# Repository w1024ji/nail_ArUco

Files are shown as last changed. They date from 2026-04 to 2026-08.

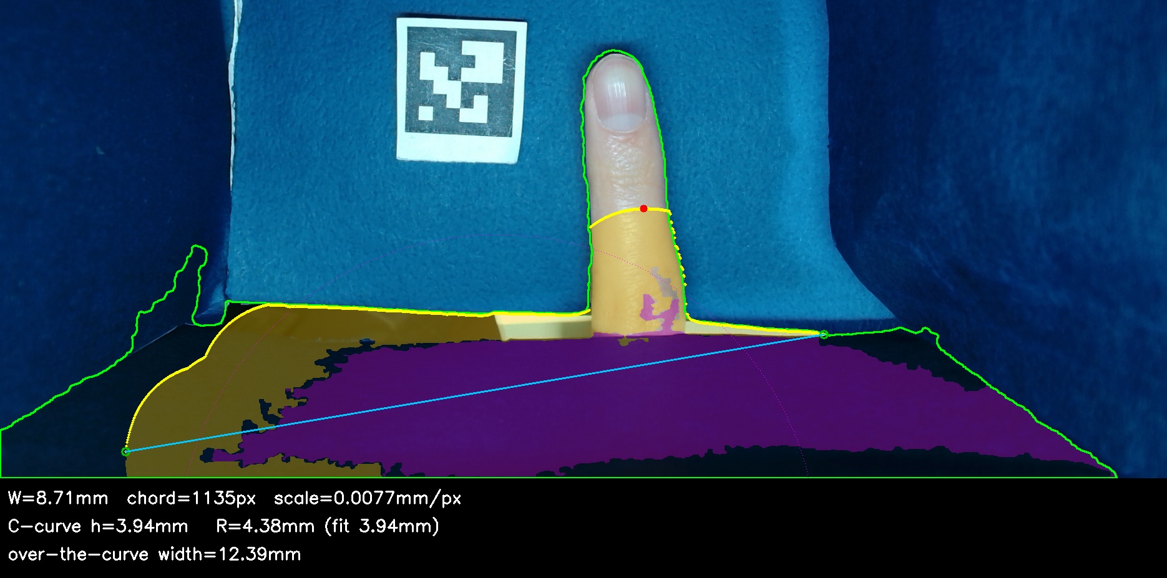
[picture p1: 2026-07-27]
scan/out_live/index_ccurve_debug.jpg

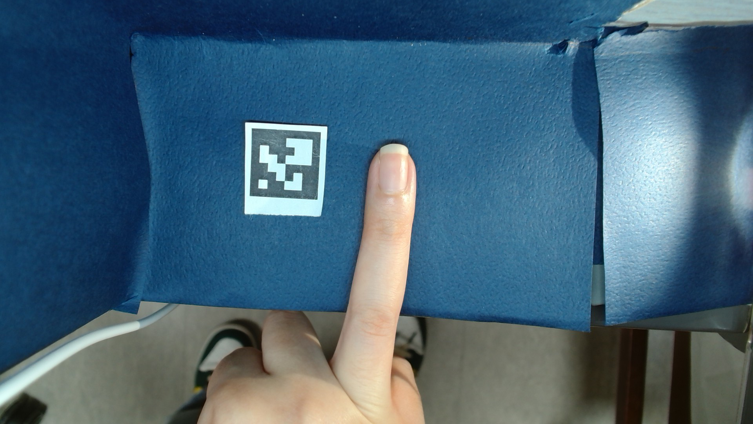
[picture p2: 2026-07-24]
scan/test/test_ring_a.jpg

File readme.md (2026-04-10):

# Nail Measurement Tool
### ArUco-based · 5 fingers · JSON output for 3-D mesh pipeline

---
## commands
```bash
python nail_measurer.py --image fingers_left.jpg --aruco-size 20 --output my_results_left
python nail_tip_generator.py --measurements nail_measurements.json --hand right --curve flat
python nail_tip_generator.py --measurements nail_measurements.json --hand right --curve medium
python nail_tip_generator.py --measurements nail_measurements.json --hand right --curve steep
```

---

## Install

```bash
pip install opencv-python opencv-contrib-python numpy scipy
```
Python 3.10+ recommended.

---

## Quick-start workflow

### 1 · Print a marker

```bash
python generate_aruco.py --size 20 --id 0 --output marker.png
```
- Print `marker.png` at **100 % scale** (no "fit to page").
- Verify the inner black square with calipers. Note the exact mm value.

### 2 · Take the photo

| ✅ Do | ❌ Avoid |
|---|---|
| Hand flat, palm down | Tilted or angled shots |
| Marker in the same plane as nails | Marker propped up / on a book |
| Diffuse even lighting | Harsh shadows across nails |
| Plain light-coloured background | Patterned tablecloth |
| Shoot straight down (top-view) | Side angle |
| 12 MP+ camera | Low-res or blurry |

### 3 · Run auto-detection

```bash
python nail_measurer.py --image hand.jpg --aruco-size 20.3 --output results/
```
*(use your actual caliper measurement for `--aruco-size`)*

Output: `results/nail_measurements.json`

### 4 · Manual fallback (painted nails / poor lighting)

```bash
python manual_selector.py --image hand.jpg --aruco-size 20.3 --output results/
```
- **Left-click** to place outline points around a nail
- **Right-click** to save and move to the next finger
- **`u`** to undo last point
- **`n`** to skip a finger
- **`q`** or **ESC** to finish

---

## JSON output structure

```jsonc
{
  "meta": {
    "source_image": "hand.jpg",
    "aruco_marker_id": 0,
    "aruco_physical_size_mm": 20.3,
    "mm_per_pixel": 0.07314,
    "nails_detected": 5,
    "measurement_notes": { ... }   // explains each field
  },

  // Full detail per nail
  "nails": [
    {
      "finger":            "thumb",
      "finger_id":         0,
      "length_mm":         16.4,
      "width_mm":          14.2,
      "c_curve_mm":        2.3,     // arc depth (sagitta)
      "arc_radius_mm":     23.1,    // radius of curvature
      "thickness_mm":      0.45,    // estimated (see note)
      "thickness_source":  "geometric_estimate",
      "aspect_ratio":      0.866,
      "pixel_scale_mm_per_px": 0.07314,
      "nail_polygon_px":   [[x,y], ...]
    }
    // ... index, middle, ring, pinky
  ],

  // Quick lookup by finger name
  "by_finger": {
    "thumb":  { "length_mm": 16.4, "width_mm": 14.2, ... },
    ...
  },

  // Ready-to-use 3-D mesh parameters
  "mesh_params": {
    "thumb": {
      "bounding_box_mm": { "x": 14.2, "y": 0.45, "z": 16.4 },
      "curvature": {
        "c_curve_sagitta_mm": 2.3,
        "arc_radius_mm":      23.1
      },
      "shape_hint": "barrel_arc  AR=0.866"
    },
    ...
  }
}
```

---

## Measurements explained

| Field | Definition | How it's computed |
|---|---|---|
| `length_mm` | Base-to-tip along the nail's long axis | Rotated bounding box long side |
| `width_mm` | Widest point across the nail | Rotated bounding box short side |
| `c_curve_mm` | Arc depth (sagitta) — how much the nail curves across its width | Max perpendicular deviation from the width chord |
| `arc_radius_mm` | Radius of the circular arc | Sagitta formula: R = w²/(8h) + h/2 |
| `thickness_mm` | Nail plate thickness base-to-surface | Estimated: c_curve × 1.5, clamped to 0.25–0.85 mm |

### Thickness note
Thickness **cannot** be measured from a top-down photo alone.
The value in the JSON is a geometric estimate based on nail anatomy research
(average human nail: 0.35–0.65 mm).
For precision 3-D printing, measure thickness from a **side-view** photo:
```bash
# future: side_view_measurer.py --image thumb_side.jpg --aruco-size 20.3
```
Then manually update `thickness_mm` in the JSON.

---

## Using the JSON in your 3-D pipeline

The `mesh_params` block gives you everything needed to construct a parametric nail mesh:

```python
import json

with open("nail_measurements.json") as f:
    data = json.load(f)

for finger, params in data["mesh_params"].items():
    bb  = params["bounding_box_mm"]   # x=width, y=thickness, z=length
    R   = params["curvature"]["arc_radius_mm"]
    h   = params["curvature"]["c_curve_sagitta_mm"]
    # → feed bb + R into your parametric nail mesh generator
```

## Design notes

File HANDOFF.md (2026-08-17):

# Nail ArUco — Handoff (2026-08-10)

Custom nail-tip generator: photo of a finger → real-world measurements → 3D-printable STL. Written for picking this project back up on a new Claude account. Repo: `/mnt/c/nail_ArUco`, branch `nail-shape-detection`.

## Pipeline

1. **Photo/Capture** — one finger per shot, finger pointing up, ArUco marker (6x6_50 dict) beside it on the same flat surface, dark background.
   - `scan/nail_capture.py` — auto-capture still-photo flow (marker stability + skin-fraction gate before countdown).
   - `scan/nail_live.py` — **preferred now.** Runs measurement continuously on the live camera feed; operator presses ENTER to accept the measurement they're looking at (not a raw photo to be judged blind afterwards). Has a `--rotate {0,90,180,270}` flag because the rig's camera is mounted upside down. Shows a live fold-coverage meter and a peak-width tracker (see below).
2. **Measure** — `scan/nail_measurer.py` (the core, heavily-tuned module). ArUco gives mm/px scale; then detects finger silhouette, nail width (lateral folds), length, cuticle position, and c-curve. Outputs `nail_measurements.json` + `profile.json` + annotated image.
3. **C-curve (separate, end-on shot)** — `scan/measure_ccurve.py`, needs a photo looking straight at the fingertip. Not yet integrated into the box rig (see Open Problems).
4. **Generate STL** — `scan/nail_exact_stl.py` (primary; v15-ish internally) turns the JSON into a parametric watertight STL. Shapes: round, almond, square, stiletto, ballerina, oval.
5. **Arrange for printing** — `printer/merge_fingers.py` (new, untracked as of this handoff) loads the 5 finger STLs, tilts + spaces them, exports one `.3mf` for the slicer.
6. **Upload** — `scan/s3_upload.py`. **Upload-only, on purpose** — never add delete/sync logic here; a local mistake could wipe the S3 bucket. This was an explicit user decision, don't revisit it.

## Where things stand (measurement accuracy)

Validated against ruler ground truth (`scan/sh_images/`, see details below): width and length both land within **±0.5–0.9mm** of a ruler on well-lit reference photos. The box rig (in-progress hardware) is not yet at that accuracy — see below.

### The central finding: light direction decides what's detectable
A groove only casts a shadow when light rakes **across** it, not along it.
- **Lateral nail folds** (run vertically along the finger) need light from the **side** (left/right).
- **Cuticle** (runs horizontally across the finger) needs light along the **finger axis** (from the tip or base end), and is actually found by *pigment color* now, not shadow (see below), so it's lighting-independent as long as it's not blown out.
- These two needs conflict — one side light can't reveal both. Plan: two lights, switchable, ideally two frames per finger using whichever light reveals that feature.
- The code's own header comment ("even lighting, no harsh shadows") is **wrong** for this pipeline and should eventually be corrected/removed.

### Width — from lateral nail folds
`detect_lateral_edges()` in `nail_measurer.py` finds the fold groove via a color/texture ridge (`S/12 + a*/4 - L/12`), validated by requiring skin on both sides of a candidate peak (distinguishes a real groove from the finger's outer silhouette, which only has skin on one side).
- Needs a raking side light. Target: skin brightness gradient (L\*) **~40+** between the lit and shadow side of the finger, and lit-side L\* around ~195 with near-0% clipped (overexposed) pixels — overexposing erases the very shadow the detector needs.
- If fold coverage is too low, width silently falls back to the plain finger-silhouette mask, which is measurably worse (this was traced as the main driver of instability in earlier box-rig tests).
- `nail_live.py`'s on-screen meter shows live fold-coverage % and lit-side clipping % so the operator can aim the light while watching the numbers — use this when tuning the new box's LEDs.
- Width is also foreshortened by finger roll (rotation about its long axis) and this is invisible in the overlay — `nail_live.py` tracks a rolling peak-W window and shows SQUARE-ON vs ROLLED so the operator rolls the finger until W stops increasing.
- **Known noise issue**: width is *bistable* under small pixel noise / JPEG re-compression — it can flip between two discrete values ~0.6mm apart on a sizeable minority of frames (root cause not fully isolated, lives somewhere in the row-scan width path). Fix in place: `nail_live.py` takes a **median across several accepted frames** rather than trusting one. This is the strongest reason the live-camera flow exists at all — a single static photo can't average.

### Cuticle — from color, not shadow
`detect_cuticle_by_color()` finds the cuticle by pigment: a\* (redness) dips to a local minimum right at the cuticle, and b\* (yellowness) climbs just below it (skin is more yellow than nail plate). Score = `(b_rise) + (a_dip)`; this beat either signal alone on every test photo, and it works regardless of light direction. Search window is built from the *measured* width, not a fixed anthropometric ratio (see below).

### The W/L "Jung plate ratio" 0.91 prior is wrong — don't reintroduce it
An old assumption that cuticle-to-tip length ≈ width / 0.91 is baked into `WL_STANDARD` / `corrected_length_mm` / `apply_wl_correction()`. Ruler ground truth shows the *true* ratio is more like 0.64–0.86 depending on finger, and using 0.91 as ground truth actively corrupts results (it shrank a true 14mm-long thumb print down to 12.65mm on one test). Current code measures cuticle/length directly and only uses the 0.91-based path as a last-resort fallback. If you see width/length numbers that look "corrected" back toward a suspicious ratio, that's this legacy prior leaking back in — don't retune it, trust the direct measurement instead.

### End-on c-curve (dome curvature)
`measure_ccurve.py` needs a photo looking straight at the fingertip (not top-down), fits a circle to the free-edge band, gets sagitta `h` and radius `R`. Validated once (sh_middle: h=2.38mm, R=6.06mm, matched ruler within ~0.1mm). **The current box rig cannot produce this view** — the finger enters from below toward a wall-mounted marker, so there's no way to point the fingertip at the camera inside it. Runs are currently top-view only (no `--ccurve`), and STL dome curvature from box-rig runs should not be trusted yet — that's real open work for the new box design if you want accurate c-curve without a second manual shot.

## Print-fit corrections (from real test prints, `nail_exact_stl.py`)
These are empirical corrections layered on top of the *measured* geometry (only in normal mode — `--exact` mode skips all of them and prints a true replica for validation):
- **Width**: printed nail was smaller than real even at +0, because bending flat measured width into the 3D C-curve shrinks the wrapping chord. Fix: add `WIDTH_FIT_MARGIN_MM = 3.0` before building geometry.
- **Length**: was printing ~4mm short — root cause was the bad 0.91 prior described above overriding the real measured length. Fixed by preferring measured length; do not re-add a flat "+4mm" band-aid, that was the wrong fix and has been removed.
- **Cuticle-curve blend**: an attempt to round the inner base near the cuticle. Currently **off by default** (`--cuticle-curve 0.0`) — user reported it "not working". Code is still there, dormant, if you want to revisit.
- **Thickness default**: 0.6mm (down from 1.2mm), per request.

## Open problems / where to focus next (given the new box build)
1. **Get the side light right first** — this is the single biggest lever on width accuracy right now. Aim for the ~40+ L\* gradient target above and watch `nail_live.py`'s coverage meter live while positioning LEDs. Don't make the box interior uniformly diffuse/matte-white — that recreates flat lighting and kills the fold shadow the whole method depends on.
2. **Cuticle-axis light** — currently unaddressed in the box; a second, switchable light along the finger's long axis was the plan but wasn't built as of the last session. Not strictly required now that cuticle detection is color-based rather than shadow-based, but worth checking that the color signal isn't getting washed out by whatever light is on.
3. **End-on c-curve capture** — the box's finger-from-below geometry blocks this shot entirely. If you want in-box c-curve, the new box needs either a second camera position/angle or a way to present the fingertip to the main camera.
4. **Width bistability** — root cause not fully pinned down (something in the row-scan / width path is sensitive to single-pixel noise). Currently papered over by median-of-N-live-frames; worth root-causing properly if you have time, since it would let single-photo capture become reliable again.
5. **`printer/merge_fingers.py`** is new and not yet committed to git — review/commit it if it's in a good state, or continue iterating on plate layout (tilt/spacing constants at the top of the file).

## Practical gotchas
- No `cv2` in WSL python — everything must run under Windows Python: `/mnt/c/Users/USER/AppData/Local/Programs/Python/Python311/python.exe`.
- Environment variables do **not** propagate from WSL to Windows Python — gate any debug flags on `sys.argv`, not `os.environ`.
- Windows Python cannot write to WSL `/tmp` paths — write debug/scratch files inside the repo instead (e.g. `scan/test/`).
- Live capture must measure at the exact resolution that will be accepted (never downscale for speed) — measurement is resolution-sensitive; the same photo gave wildly different widths at 640/960/1280/1920px.
- Accept/save frames as **PNG**, never JPEG — JPEG re-encoding alone can flip the bistable width or shift c-curve sagitta.
- ArUco marker is **DICT_6X6_50**, printed once via `generate_aruco.py`. Always pass the true printed `--aruco-size` — a wrong value scales every measurement linearly and the overlay will still look plausible.

## Reference: ruler ground truth (sh_images)
| nail | width (from above) | width incl. c-curve | length |
|---|---|---|---|
| sh_thumb | 12mm | 13mm | 14mm |
| sh_middle | 9mm | 11mm | 14mm |

Pipeline came within ±0.5mm on width for both (thumb 11.51 vs 12, middle 9.50 vs 9) and ±0.9mm on length across several test photos.

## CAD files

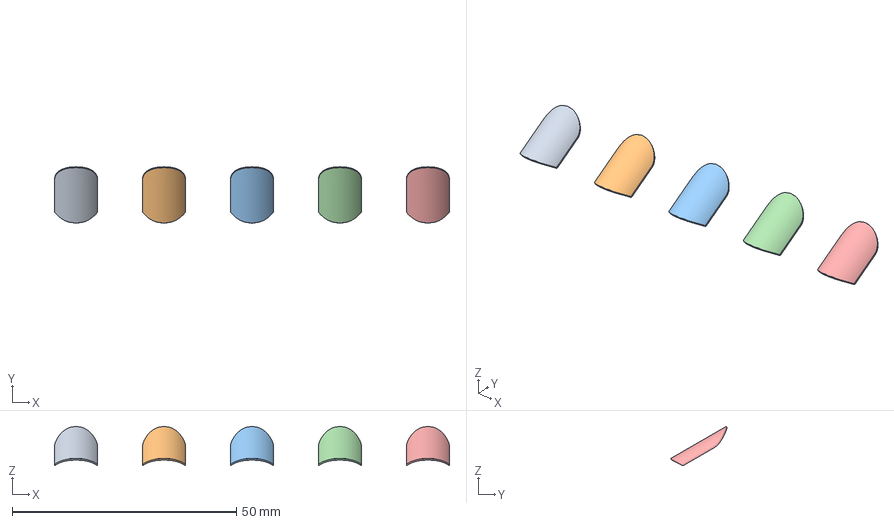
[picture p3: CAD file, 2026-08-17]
printer/output/hand_merged.3mf
88.2 x 12.6 x 8.78 mm
nail_thumb_round
nail_index_round
nail_middle_round
nail_ring_round
nail_pinky_round

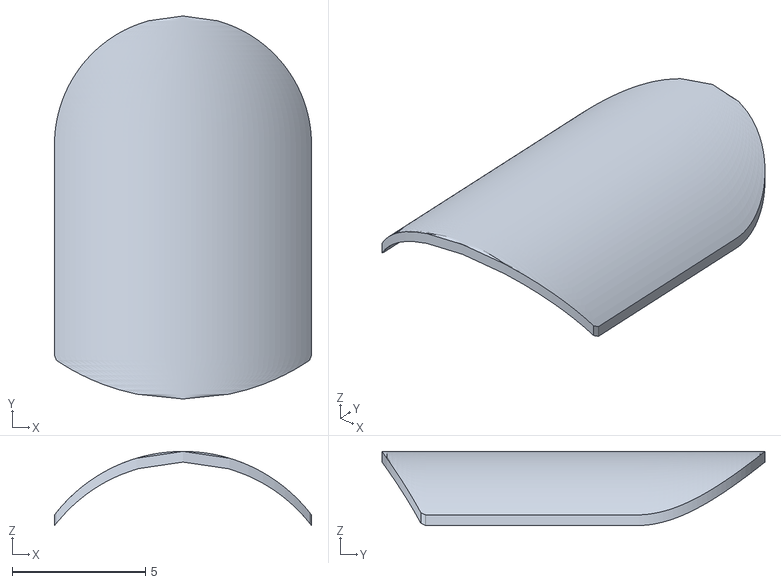
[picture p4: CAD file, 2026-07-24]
printer/stl/nail_middle_round.stl
9.63 x 14.4 x 2.78

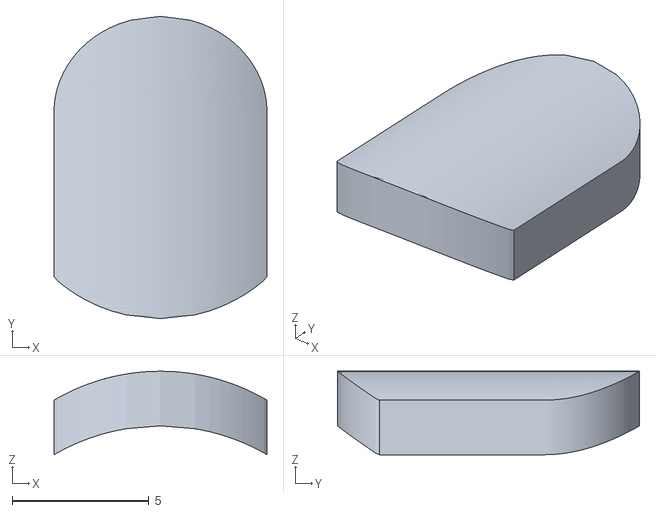
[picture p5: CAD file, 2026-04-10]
results/middle/stl/nail_middle_exact.stl
7.80 x 11.1 x 3.06

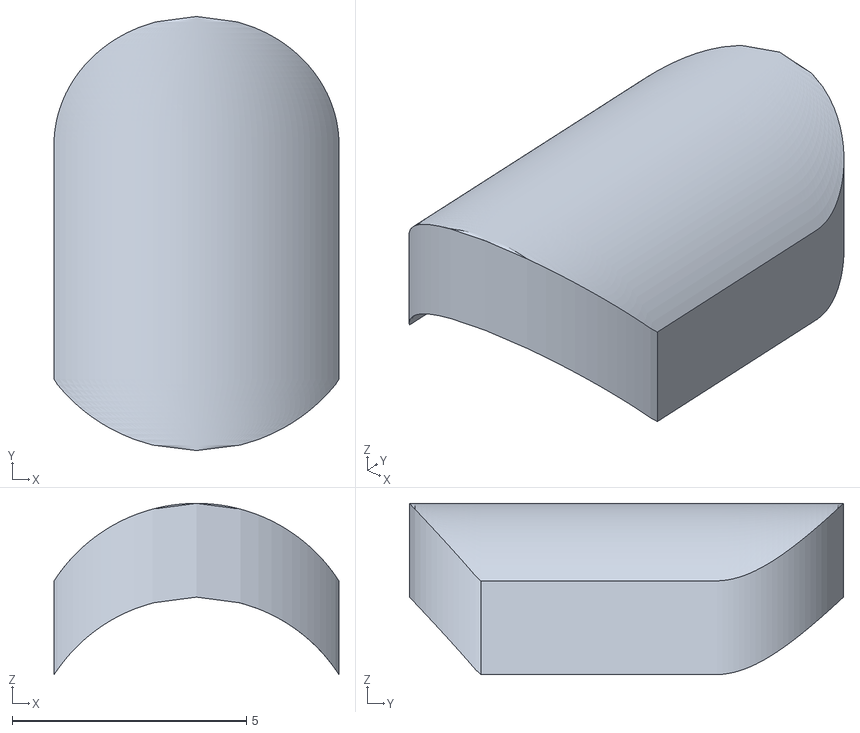
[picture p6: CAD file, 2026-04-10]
results/pinky/stl/nail_pinky_exact.stl
6.08 x 9.26 x 3.65

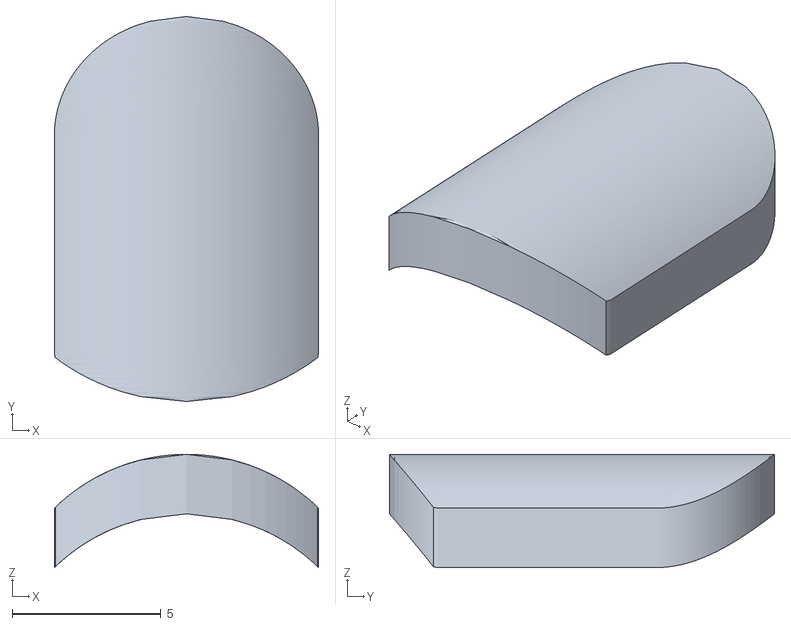
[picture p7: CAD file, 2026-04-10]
results/stl_v15/nail_index_exact.stl
8.89 x 12.9 x 3.81

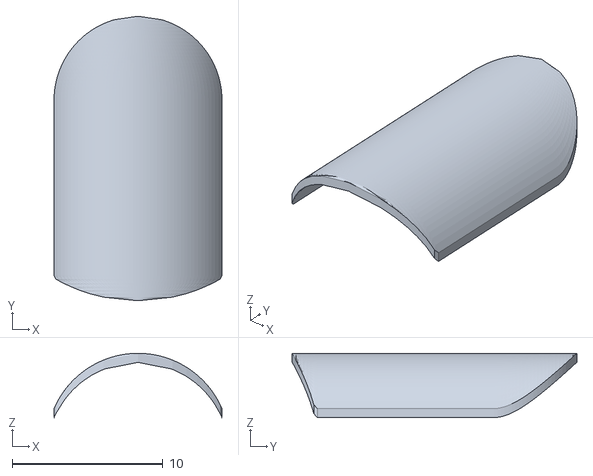
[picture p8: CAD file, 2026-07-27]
scan/out_sh_middle_version2/stl/nail_middle_round.stl
11.1 x 18.9 x 4.26

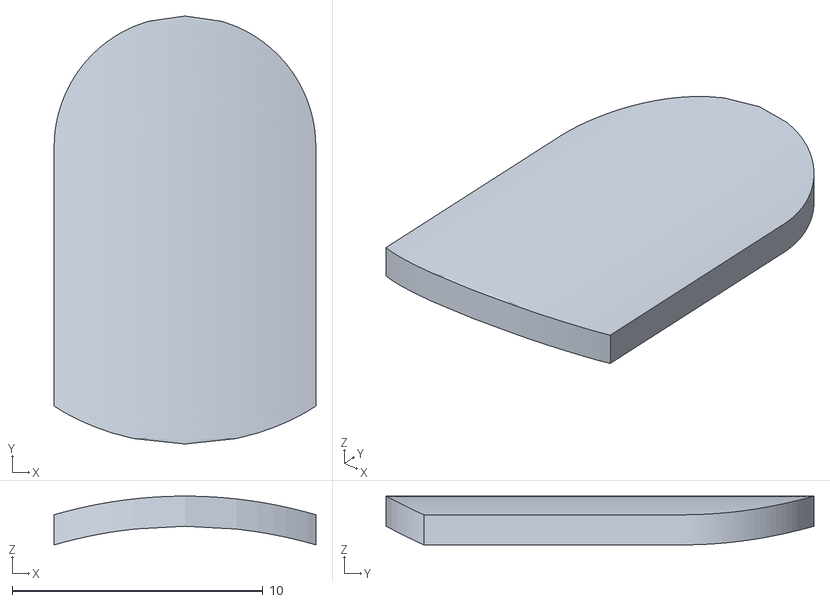
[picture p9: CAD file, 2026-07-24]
scan/out_sh_thumb_version3/stl/nail_thumb_round.stl
10.4 x 17.1 x 1.94

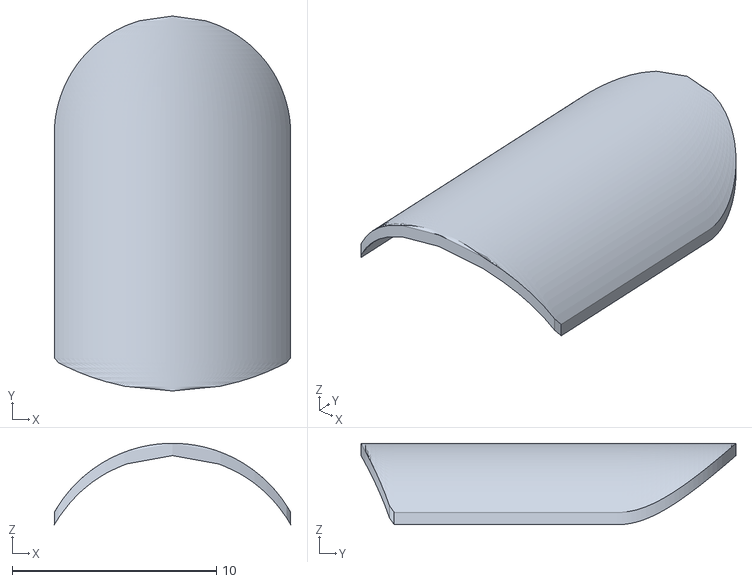
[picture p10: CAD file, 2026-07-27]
scan/out_ys_index/stl/nail_index_round.stl
11.6 x 18.4 x 3.98

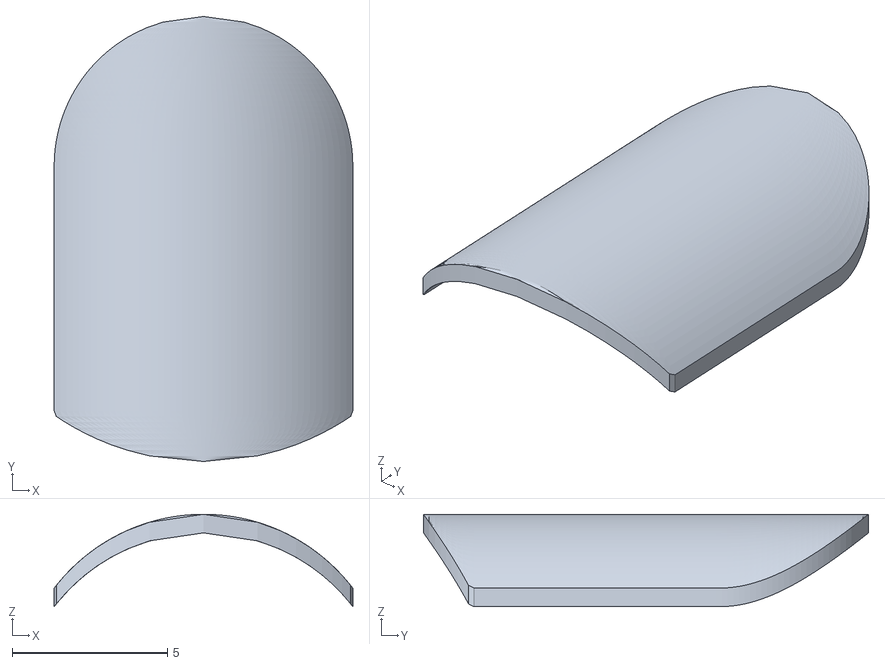
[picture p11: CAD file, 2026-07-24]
scan/out_sh_middle_version2/stl/nail_middle_round_t0.6.stl
9.63 x 14.4 x 2.98

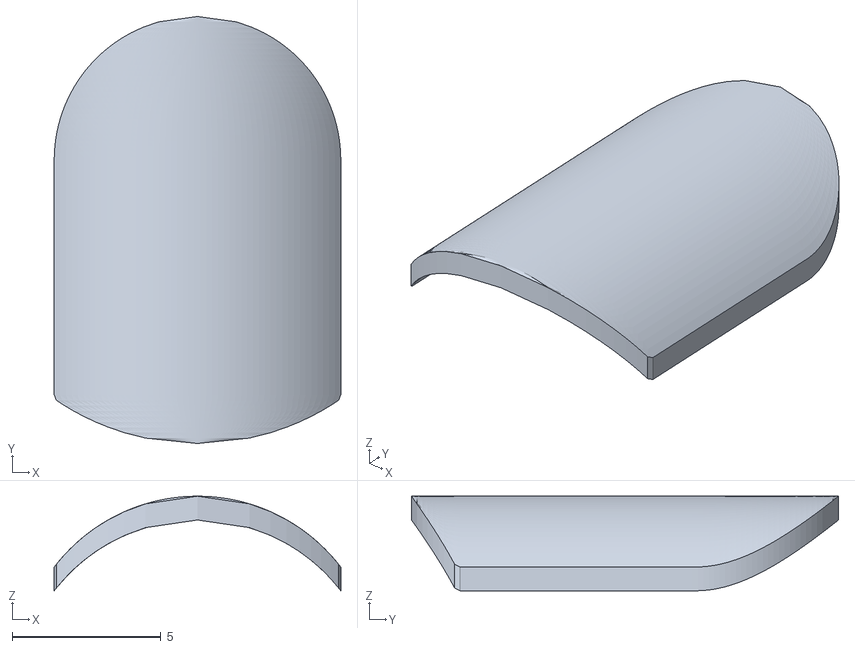
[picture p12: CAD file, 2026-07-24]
scan/out_sh_middle_version2/stl/nail_middle_round_t0.8.stl
9.63 x 14.4 x 3.18

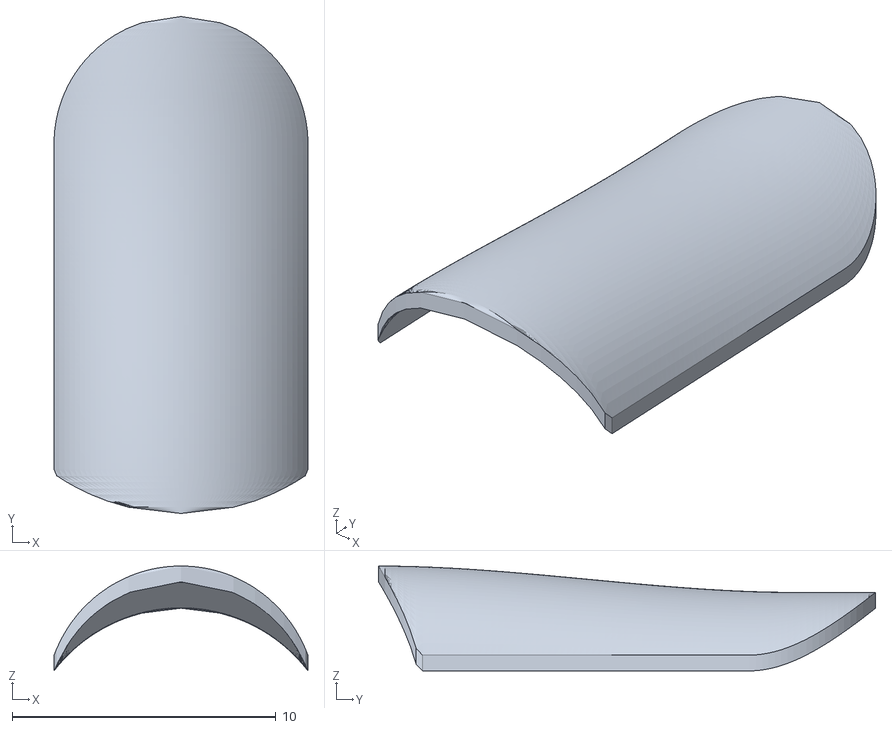
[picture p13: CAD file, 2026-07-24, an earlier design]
scan/out_sh_middle_version2/stl_v3/nail_middle_round_cuticlecurve+1.0_t0.6.stl
9.63 x 18.9 x 3.98

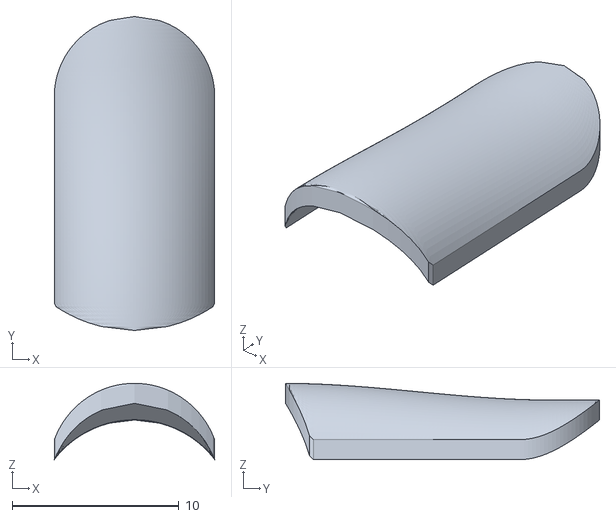
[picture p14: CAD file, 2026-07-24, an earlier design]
scan/out_sh_middle_version2/stl_v3/nail_middle_round_cuticlecurve+1.0.stl
9.63 x 18.9 x 4.58

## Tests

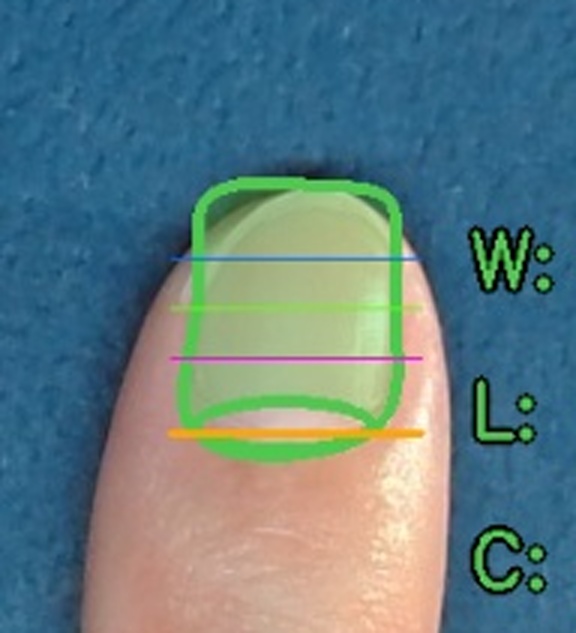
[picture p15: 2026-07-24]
scan/test/out_test_index_b/zoom.jpg

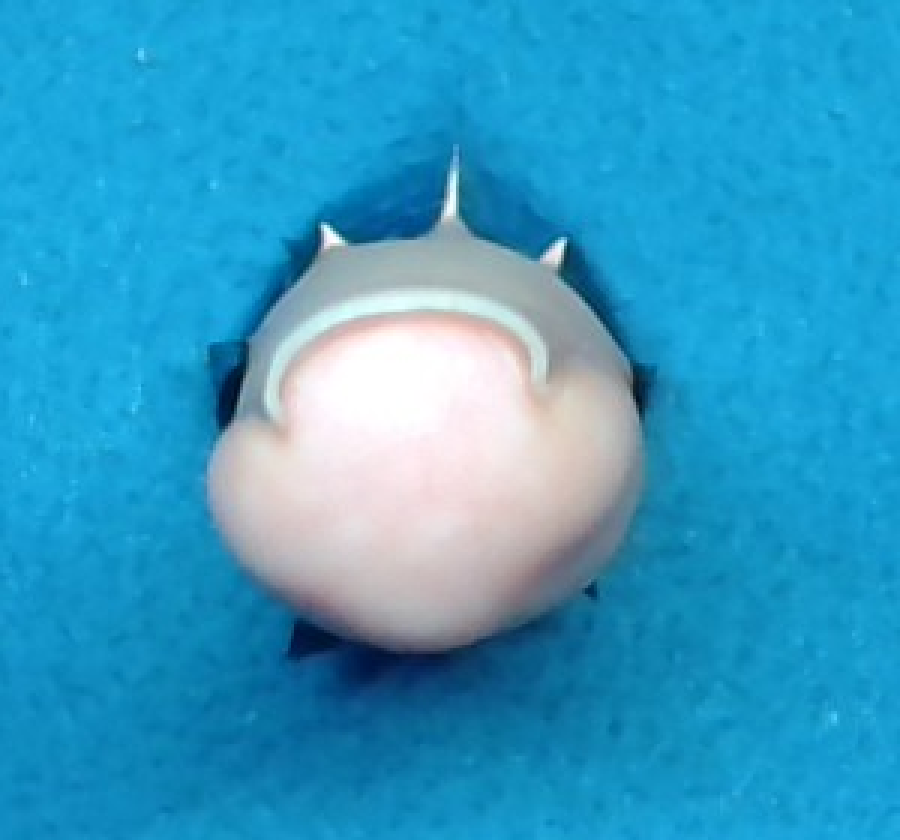
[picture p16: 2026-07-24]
scan/test/ccurve_zoom.png

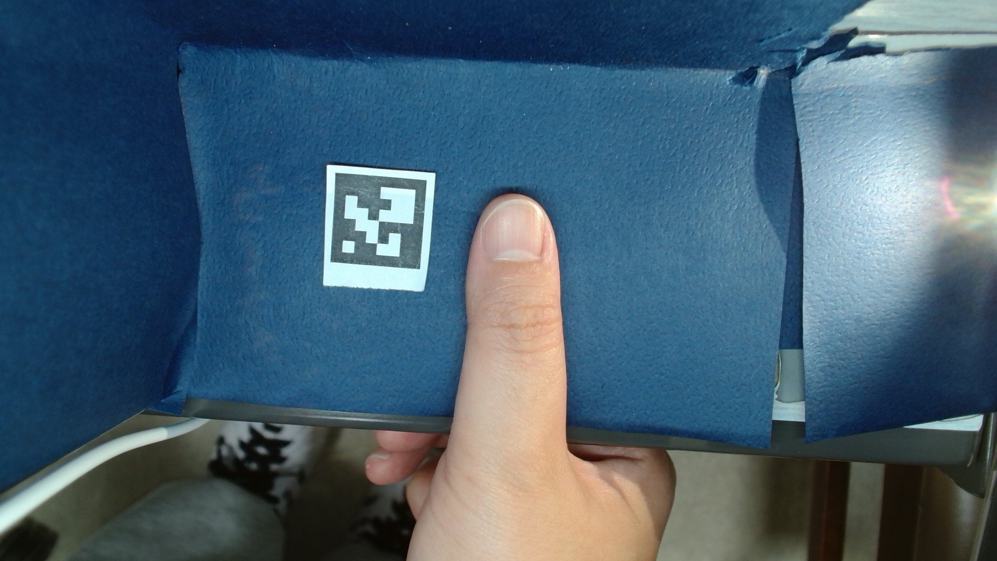
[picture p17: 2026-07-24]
scan/test/test_thumb_b.jpg

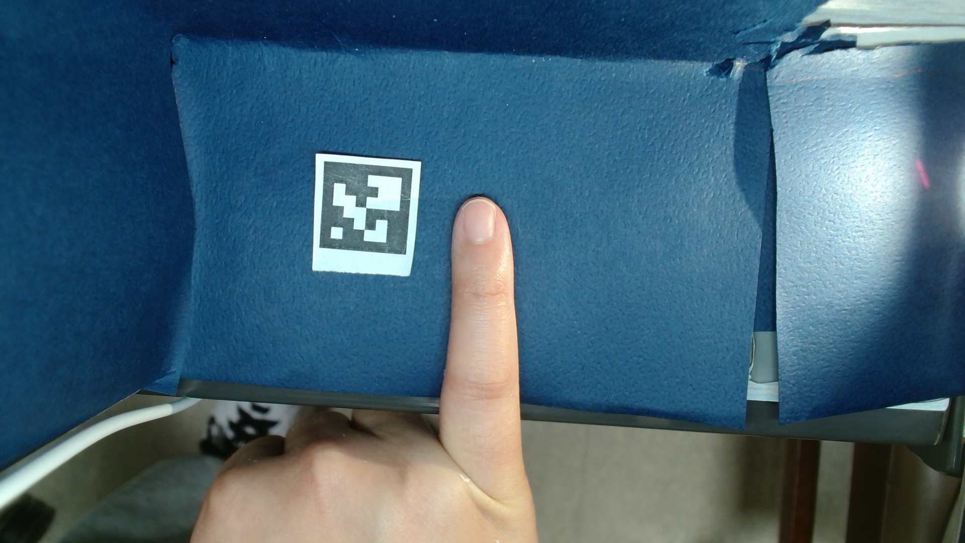
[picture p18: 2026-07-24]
scan/test/test_pinky_b.jpg

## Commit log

2026-03-12 success3 generate stl files for each nails
    [nail_tip_middle.stl]
2026-03-19 added directories and standard finger size
    [nail_tip_index.stl, nail_tip_middle.stl, nail_tip_pinky.stl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]
2026-03-19 big or small info is in print_manifest.json
2026-03-19 deleted unused files
    [nail_tip_middle.stl]
2026-03-20 label hand as short or long and adjust stl files with c-curve condiserations
    [nail_tip_index.stl, nail_tip_middle.stl, nail_tip_pinky.stl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]
2026-04-10 fix STL geometry: correct c-curve orientation and natural cuticle arc
    - nail_exact_stl.py v15: inner surface is now dome-shaped (C - arc_z)
    so it seats flush on the convex real nail; outer surface is also
    dome-shaped for a natural appearance. Cuticle arch replaced with a
    single circular arc through both side corners and the centre depth
    point, eliminating the flat-bottom bump from v14.
    - nail_shape_stl.py: polygon-based STL generator from traced outline
    - check_stl.py: geometry validation helper
    - results/: index finger measurements JSON, annotated photo, STL v11–v15
    [nail_index_exact.stl]
2026-04-10 middle and pinky success!
    [nail_index_exact.stl, nail_middle_exact.stl, nail_pinky_exact.stl]
